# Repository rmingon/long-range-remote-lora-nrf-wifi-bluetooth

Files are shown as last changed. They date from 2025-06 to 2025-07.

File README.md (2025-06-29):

# **Triple-Radio Remote Controller PCB**

A compact, hand-held remote that combines **Wi-Fi / Bluetooth (ESP32)**, **2.4 GHz nRF24L01+** and **868/915 MHz LoRa (RFM95W)** in a single, joystick-style board.  
It is intended as a flexible radio interface for robotics, drones, RC models, telemetry links or IoT experimentation where different wireless technologies are useful at once.

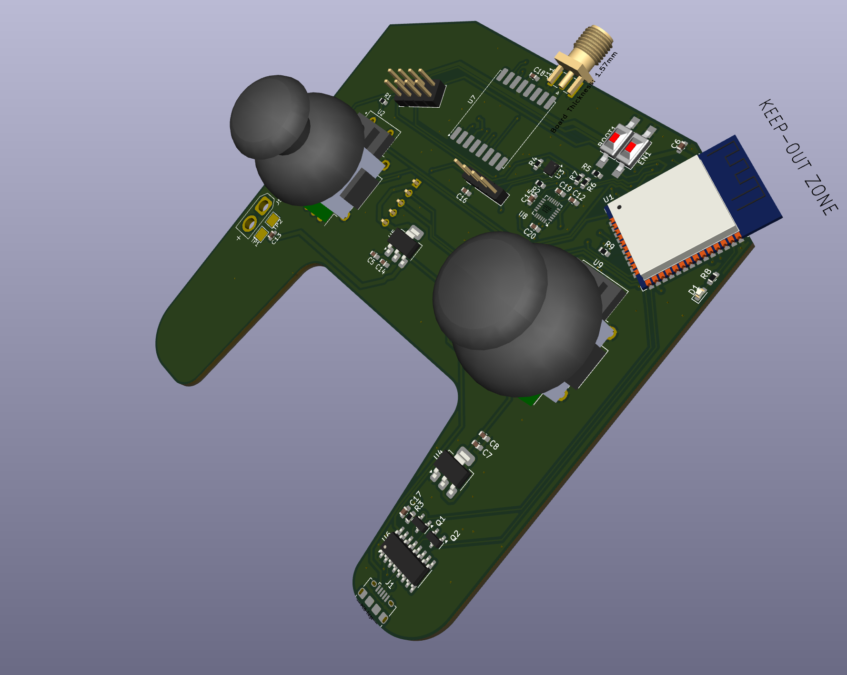
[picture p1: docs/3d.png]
3 D render
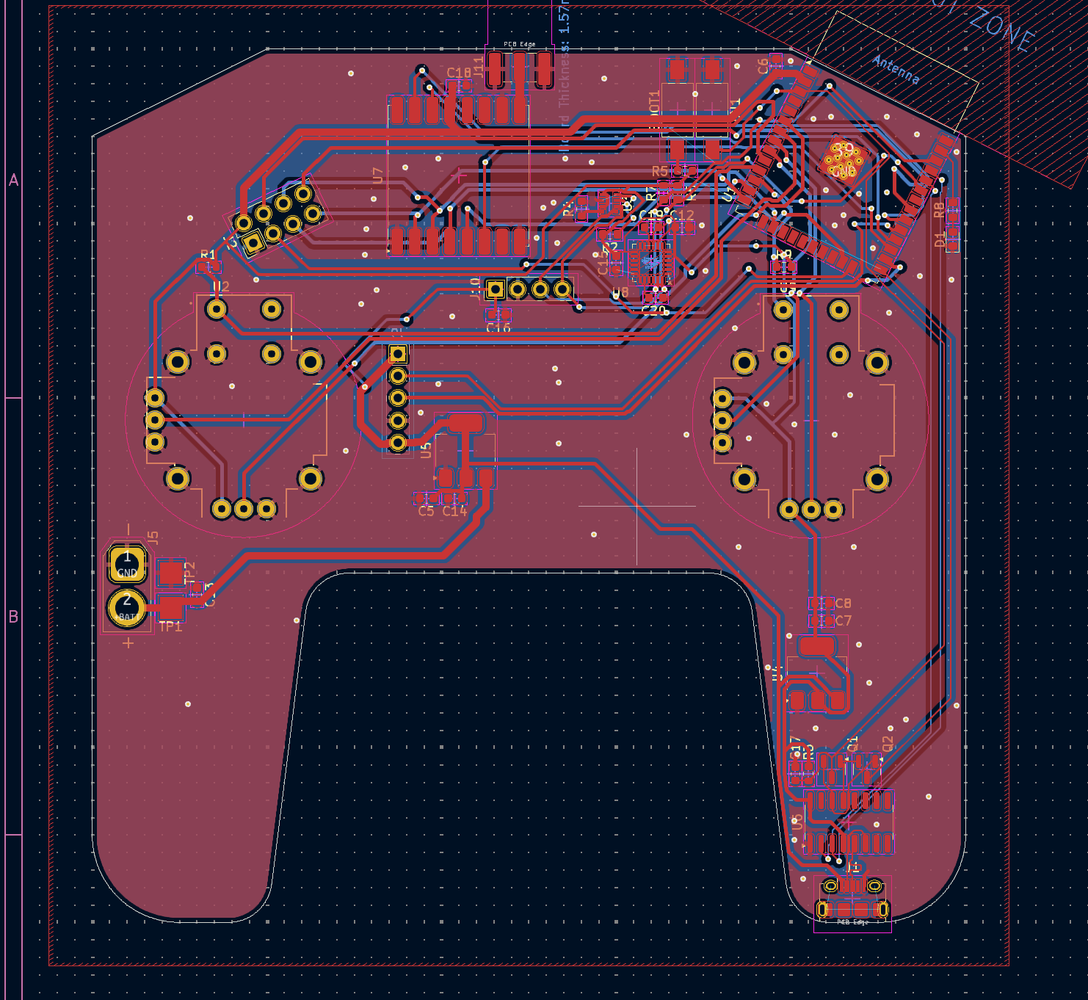
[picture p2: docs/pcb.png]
Top copper
|  |  |
| --- | --- |

---

## Table of Contents
1. [Features](#features)  
2. [Hardware Overview](#hardware-overview)  
3. [Schematic Blocks](#schematic-blocks)  
4. [Power Architecture](#power-architecture)  
5. [Pin Map](#pin-map)  
6. [Firmware](#firmware)  
7. [Getting Started](#getting-started)  
8. [Directory Layout](#directory-layout)  
9. [Road-Map](#road-map)  
10. [License](#license)

---

## Features
* **MCU — ESP32-WROOM-32**  
  * Dual-core Xtensa @ 240 MHz, 520 KB SRAM  
  * Integrated Wi-Fi 802.11 b/g/n + Bluetooth Classic/LE  
* **Radios**  
  * **nRF24L01+** – 2.4 GHz packet radio via 8-pin vertical socket  
  * **RFM95W** – Semtech SX1276 LoRa transceiver, SMA edge connector (keep-out ensured)  
* **Controls**  
  * Dual analog thumb joysticks (SparkFun COM-09032) with push-buttons  
  * One user LED (GPIO-controlled)  
* **Sensors**  
  * **MPU-6050** 6-axis IMU (gyro + accel)  
  * **BMP-280** barometric pressure / temperature sensor  
* **USB & Programming**  
  * On-board CH340C USB-to-UART with auto-reset/boot circuitry  
  * Standard USB-C connector (5 V input & data)  
* **Power**  
  * 2-pin JST-PH for Li-Ion/Li-Po battery (“+BATT”)  
  * AMS1117-3 V3 LDO for logic / radios  
  * AMS1117-5 V rail for external accessories (ESC, servos, etc.)  
  * Reverse-polarity and inrush-limit protections  
* **Expansion / Debug**  
  * 5-pin 5 V UART header  
  * 4-pin 5 V I²C header  
  * Plenty of un-populated GPIO test-pads on bottom layer  
* Finished board: **74 mm × 74 mm**, 2-layer, ENIG, green solder-mask.

---

## Hardware Overview
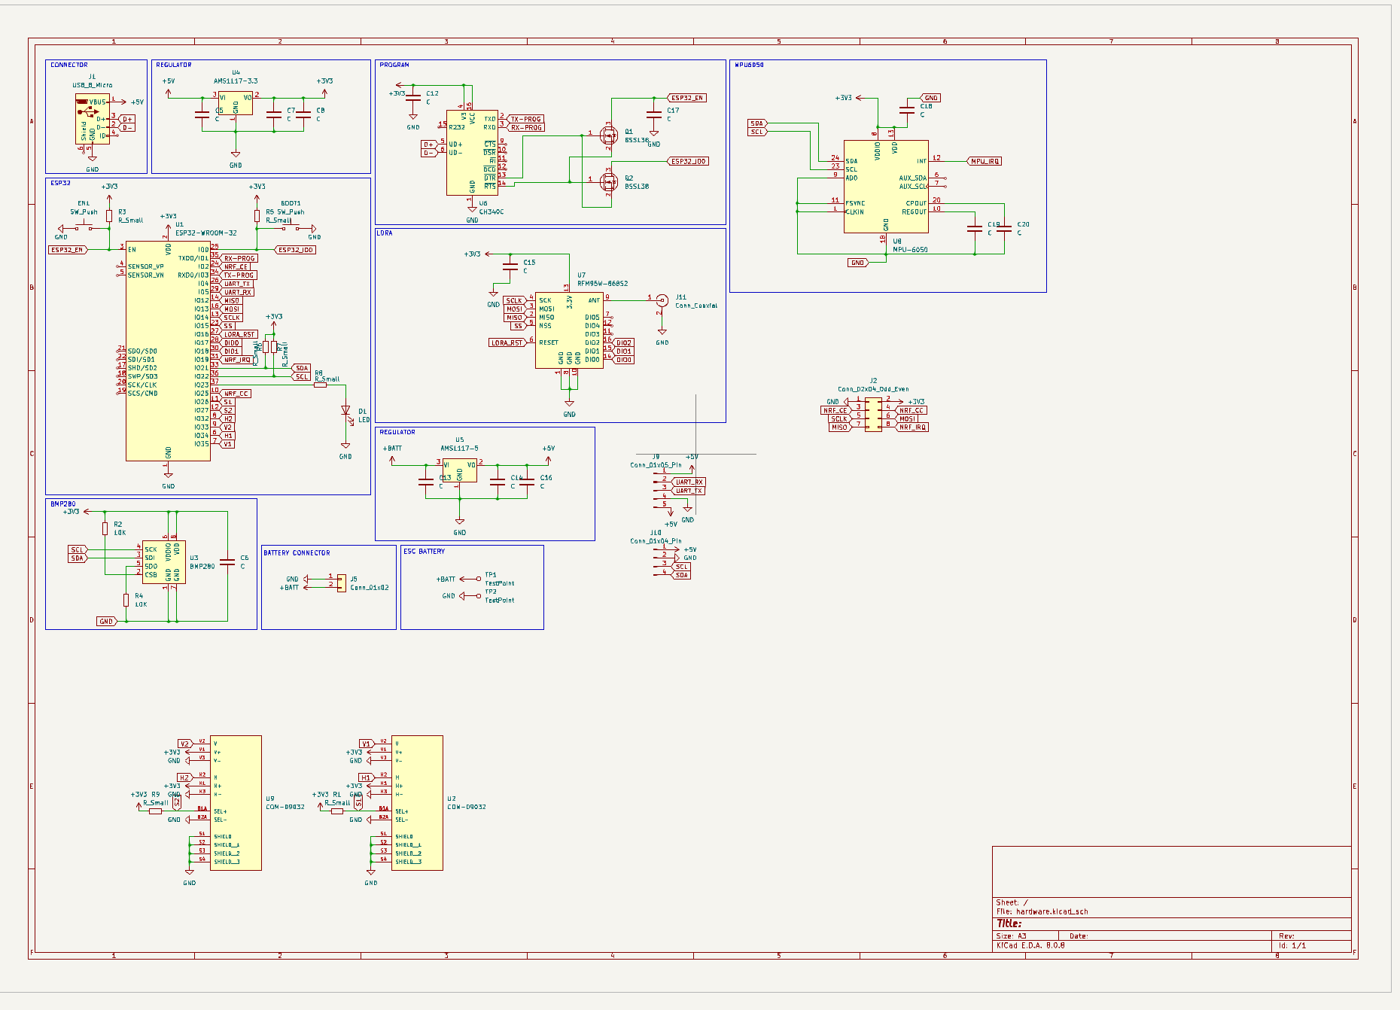
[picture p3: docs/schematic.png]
High-level block diagram


| Block | Purpose | Interfaces |
|---|---|---|
| ESP32-WROOM-32 | Central MCU; Wi-Fi/BLE | SPI, I²C, UART, ADC |
| RFM95W-868/915 | Long-range LoRa | SPI (SCK/MISO/MOSI/SS) + DIO0/1/2 + RESET |
| nRF24L01+ socket | Low-latency 2.4 GHz | Same SPI bus, CE/CSN/IRQ lines |
| MPU-6050 | Motion sensing | I²C @ 400 kHz |
| BMP-280 | Altitude / temp | I²C (wired for I²C) |
| Dual joysticks | User input | 4 × ADC + 2 × GPIO (switches) |
| CH340C | USB-UART | UART 0 (TX0/RX0), DTR/RTS auto reset |
| AMS1117-3 V3 | Logic 3.3 V rail | Up to 1 A |
| AMS1117-5 V | Aux 5 V rail | Up to 1 A |

---

## Power Architecture
```
Li-Po 2S
        │
        ├─ AMS1117-5 V ───► 5 V header / accessories
        │
        └─ AMS1117-3 V3 ──► ESP32, sensors, radios (on-board)
```
The micro-USB port supplies 5 V when plugged; if a battery is present it is **not charged** – add an external charger if required.

---

## Pin Map

| Signal | ESP32 GPIO | Notes |
|---|---|---|
| **LoRa (RFM95W)** |||
| LORA_SS (NSS) | 5 | Shared SPI SS |
| LORA_RST | 26 | Active-low reset |
| LORA_DIO0 | 34 | IRQ – input-only |
| LORA_DIO1 | 35 | Optional |
| **nRF24L01+** |||
| NRF_SS (CSN) | 33 |
| NRF_CE | 32 |
| NRF_IRQ | 27 |
| **Shared SPI bus** |||
| SCK | 18 |
| MOSI | 23 |
| MISO | 19 |
| **I²C bus** |||
| SDA | 21 | MPU-6050, BMP-280, external header |
| SCL | 22 |
| **Joysticks** |||
| Stick-L H | 36 (ADC1_0) |
| Stick-L V | 39 (ADC1_3) |
| Stick-R H | 34 (ADC1_6) |
| Stick-R V | 35 (ADC1_7) |
| Stick-L Btn | 13 |
| Stick-R Btn | 12 |
| **USB-UART** |||
| TX0 | 1 |
| RX0 | 3 |
| DTR / RTS | Auto-reset circuit |

All unused pins are broken out to pads for hacking.

---

## Firmware

Any ESP32 framework will work; the board is tested with **PlatformIO + Arduino**.  
Example `platformio.ini` snippet:

```ini
[env:esp32-remote]
platform      = espressif32
board         = esp32dev
framework     = arduino
monitor_speed = 115200
build_flags   =
  -D LORA_SS=5
  -D LORA_RST=26
  -D LORA_DIO0=34
  -D NRF_CE=32
  -D NRF_CS=33
  -D NRF_IRQ=27
lib_deps =
  sandeepmistry/LoRa
  maniacbug/RF24
  adafruit/Adafruit MPU6050
  adafruit/Adafruit BMP280 Library
```

---

## Getting Started

1. **Clone** the repository  

   ```bash
   git clone git@github.com:rmingon/long-range-remote-lora-nrf-wifi-bluetooth.git
   cd long-range-remote-lora-nrf-wifi-bluetooth
   ```

2. **Install PlatformIO** (VS Code extension or CLI).  
3. **Select the env** in `platformio.ini`, edit radio pins if you changed the board.  
4. **Connect micro-USB** ch340 auto-programming.  
5. Verify serial output at **115 200 baud**.

### LoRa / nRF24L01+ demos
Example sketches are in `firmware/examples/`:

* `lora_ping/` – bidirectional ping using SX1276  
* `rf24_controller/` – joystick values sent every 20 ms to a base-station  
* `wifi_update/` – OTA update via Wi-Fi AP  

Build & flash with:

```bash
pio run -e esp32-remote -t upload -d firmware/examples/lora_ping
```

---

## Directory Layout
```
.
├─ firmware/              → PlatformIO source
├─ hardware/
│  ├─ kicad/              → .kicad_pcb, .sch, libraries
│  ├─ gerber/             → ready for fabrication
│  └─ stl/                → optional enclosure models
├─ docs/
│  ├─ img/                → renders & photos used in README
│  └─ datasheets/
└─ LICENSE
```

---

## Road-Map
* Li-Po charging / fuel-gauge on-board  
* Hall-effect joysticks option  
* Enclosure with TPU grips  
* Support for 900 MHz nRF905 as fourth radio

---

## License
Hardware is released under **CERN-OHL-S v2**.  
Firmware samples are **MIT**.  
See individual source files for details.

---

*If you make something cool with this board, please open a pull-request and show it off!*

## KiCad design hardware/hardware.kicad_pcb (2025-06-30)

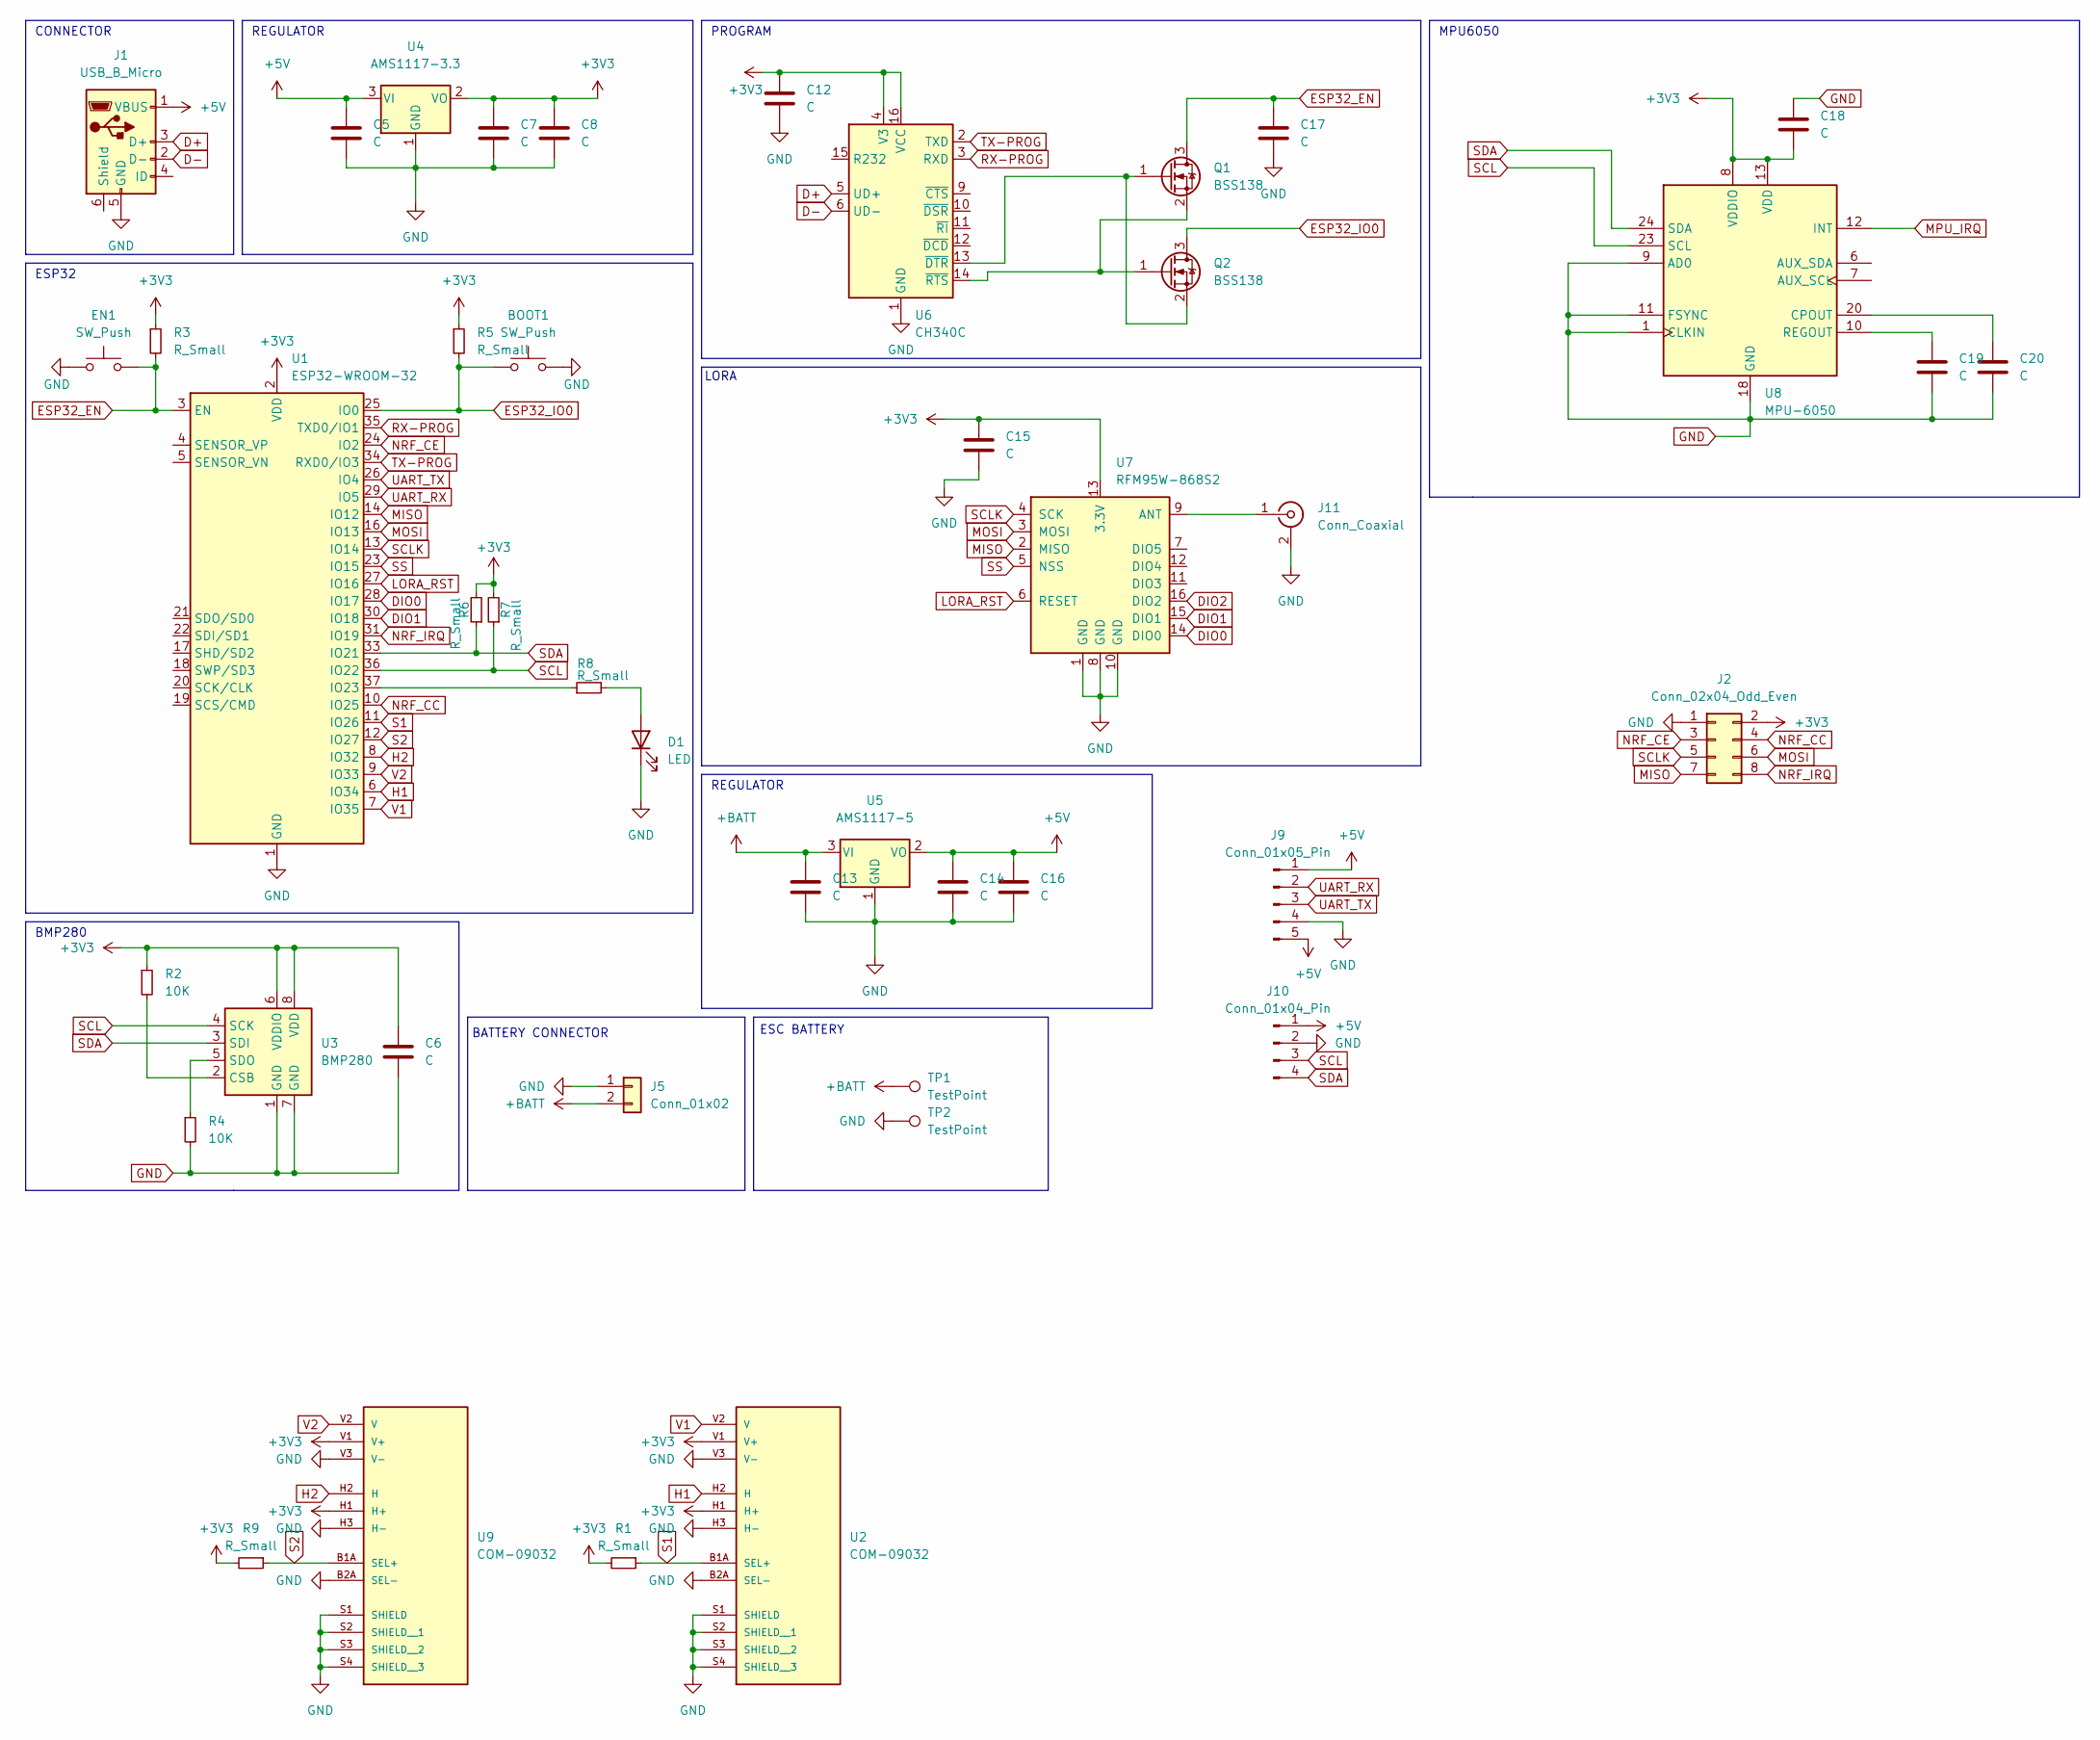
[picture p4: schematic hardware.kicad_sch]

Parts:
BOOT1: SW_Push; SW_SPST_FSMSM
C5, C6, C7, C8, C12, C13, C14, C15, C16, C17, C18, C19, C20: C; C_0603_1608Metric
D1: LED; LED_0603_1608Metric
EN1: SW_Push; SW_SPST_FSMSM
J1: USB_B_Micro; USB_Micro-B_Amphenol_10118194_Horizontal
J2: Conn_02x04_Odd_Even; PinHeader_2x04_P2.54mm_Vertical
J5: Conn_01x02; AMASS_XT30U-F_1x02_P5.0mm_Vertical
J9: Conn_01x05_Pin; PinHeader_1x05_P2.54mm_Vertical
J10: Conn_01x04_Pin; PinHeader_1x04_P2.54mm_Vertical
J11: Conn_Coaxial; SMA_Samtec_SMA-J-P-H-ST-EM1_EdgeMount
Q1, Q2: BSS138; SOT-23
R1, R3, R5, R6, R7, R8, R9: R_Small; R_0603_1608Metric
R2, R4: 10K; R_0603_1608Metric
TP1, TP2: TestPoint; TestPoint_Pad_2.5x2.5mm
U1: ESP32-WROOM-32
U2, U9: COM-09032; XDCR_COM-09032; PARTREV N/A
U3: BMP280; Bosch_LGA-8_2x2.5mm_P0.65mm_ClockwisePinNumbering
U4: AMS1117-3.3; SOT-223-3_TabPin2
U5: AMS1117-5; SOT-223-3_TabPin2
U6: CH340C; SOIC-16_3.9x9.9mm_P1.27mm
U7: RFM95W-868S2; HOPERF_RFM9XW_SMD
U8: MPU-6050; InvenSense_QFN-24_4x4mm_P0.5mm

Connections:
+3V3: C6.1, C7.1, C8.1, C12.1, C15.1, C18.2, J2.2, R1.2, R2.1, R3.1, R5.1, R6.2, R7.2, R9.2, U1.2 (VDD), U2.H1 (H+), U2.V1 (V+), U3.6 (VDDIO), U3.8 (VDD), U4.2 (VO), U6.4 (V3), U6.16 (VCC), U7.13 (3.3V), U8.8 (VDDIO), U8.13 (VDD), U9.H1 (H+), U9.V1 (V+)
+5V: C5.1, C14.1, C16.1, J1.1 (VBUS), J9.1, J9.5, J10.1, U4.3 (VI), U5.2 (VO)
+BATT: C13.1, J5.2, TP1.1, U5.3 (VI)
D+: J1.3 (D+), U6.5 (UD+)
D-: J1.2 (D-), U6.6 (UD-)
DIO0: U1.28 (IO17), U7.14 (DIO0)
DIO1: U1.30 (IO18), U7.15 (DIO1)
DIO2: U7.16 (DIO2)
ESP32_EN: C17.1, EN1.2, Q1.3 (D), R3.2, U1.3 (EN)
ESP32_IO0: BOOT1.1, Q2.3 (D), R5.2, U1.25 (IO0)
GND: BOOT1.2, C5.2, C6.2, C7.2, C8.2, C12.2, C13.2, C14.2, C15.2, C16.2, C17.2, C18.1, C19.2, C20.2, D1.1 (K), EN1.1, J1.5 (GND), J2.1, J5.1, J9.4, J10.2, J11.2 (Ext), R4.2, TP2.1, U1.1 (GND), U1.15 (GND), U1.38 (GND), U1.39 (GND), U2.B2A (SEL-), U2.H3 (H-), U2.S1 (SHIELD), U2.S2 (SHIELD__1), U2.S3 (SHIELD__2), U2.S4 (SHIELD__3), U2.V3 (V-), U3.1 (GND), U3.7 (GND), U4.1 (GND), U5.1 (GND), U6.1 (GND), U7.1 (GND), U7.8 (GND), U7.10 (GND), U8.1 (CLKIN), U8.9 (AD0), U8.11 (FSYNC), U8.18 (GND), U9.B2A (SEL-), U9.H3 (H-), U9.S1 (SHIELD), U9.S2 (SHIELD__1), U9.S3 (SHIELD__2), U9.S4 (SHIELD__3), U9.V3 (V-)
H1: U1.6 (IO34), U2.H2 (H)
H2: U1.8 (IO32), U9.H2 (H)
LORA_RST: U1.27 (IO16), U7.6 (RESET)
MISO: J2.7, U1.14 (IO12), U7.2 (MISO)
MOSI: J2.6, U1.16 (IO13), U7.3 (MOSI)
MPU_IRQ: U8.12 (INT)
NRF_CC: J2.4, U1.10 (IO25)
NRF_CE: J2.3, U1.24 (IO2)
NRF_IRQ: J2.8, U1.31 (IO19)
unnamed: D1.2 (A), R8.2
unnamed: J11.1 (In), U7.9 (ANT)
unnamed: Q1.1 (G), Q2.2 (S), U6.13 (~DTR)
unnamed: Q1.2 (S), Q2.1 (G), U6.14 (~RTS)
unnamed: R8.1, U1.37 (IO23)
unnamed: R2.2, U3.2 (CSB)
unnamed: R4.1, U3.5 (SDO)
unnamed: C20.1, U8.20 (CPOUT)
unnamed: C19.1, U8.10 (REGOUT)
RX-PROG: U1.35 (TXD0/IO1), U6.3 (RXD)
S1: R1.1, U1.11 (IO26), U2.B1A (SEL+)
S2: R9.1, U1.12 (IO27), U9.B1A (SEL+)
SCL: J10.3, R7.1, U1.36 (IO22), U3.4 (SCK), U8.23 (SCL)
SCLK: J2.5, U1.13 (IO14), U7.4 (SCK)
SDA: J10.4, R6.1, U1.33 (IO21), U3.3 (SDI), U8.24 (SDA)
SS: U1.23 (IO15), U7.5 (NSS)
TX-PROG: U1.34 (RXD0/IO3), U6.2 (TXD)
UART_RX: J9.2, U1.29 (IO5)
UART_TX: J9.3, U1.26 (IO4)
V1: U1.7 (IO35), U2.V2 (V)
V2: U1.9 (IO33), U9.V2 (V)

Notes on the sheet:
CONNECTOR
REGULATOR
MPU6050
BMP280
ESC BATTERY
LORA
PROGRAM
ESP32
BATTERY CONNECTOR

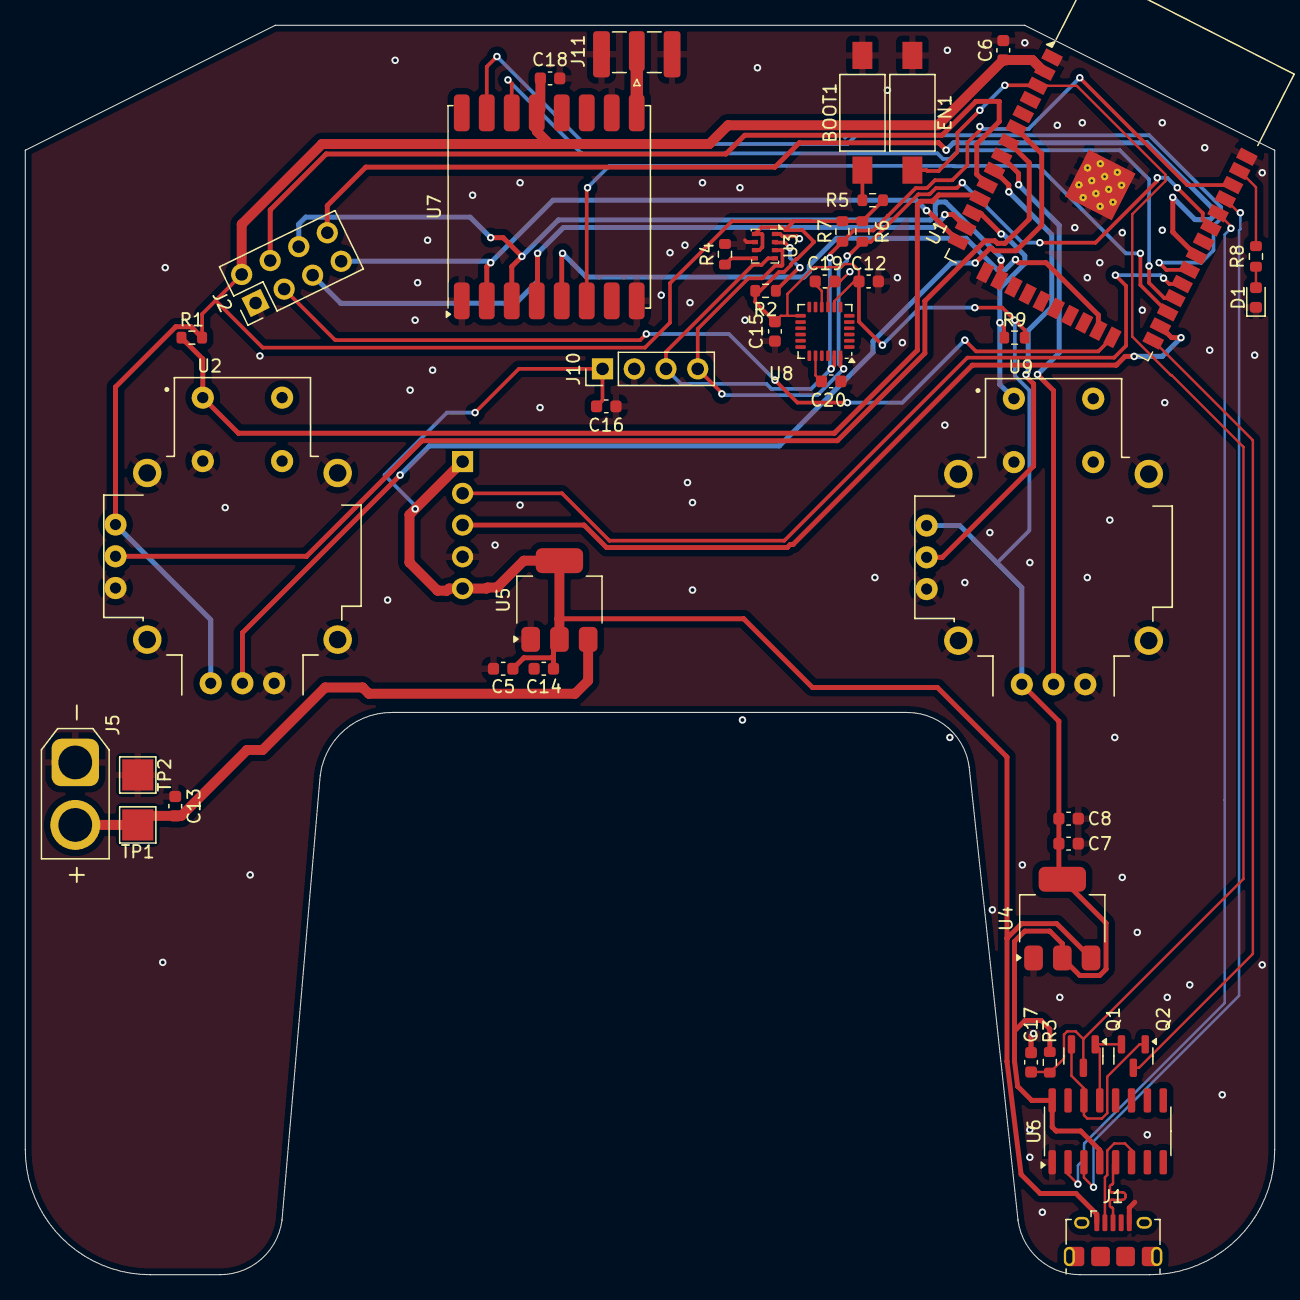
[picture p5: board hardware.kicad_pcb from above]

Board: 2 copper layers, 100.0 x 100.0 mm, 44 parts (1 on the bottom side), 39 nets.

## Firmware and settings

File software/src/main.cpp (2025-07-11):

#include <Arduino.h>
#include <SPI.h>
#include <RF24.h>
#include <ArduinoJson.h>

#define CE_PIN 2
#define CSN_PIN 25

SPIClass hspi(HSPI);
RF24 radio(CE_PIN, CSN_PIN); // Create RF24 object

#define LED 23

#define S1 26
#define H1 34
#define V1 35

#define S2 27
#define H2 32
#define V2 33

const byte address[6] = "NODE1";

void setup()
{
  pinMode(S1, INPUT);
  pinMode(H1, INPUT);
  pinMode(V1, INPUT);
  pinMode(S2, INPUT);
  pinMode(H2, INPUT);
  pinMode(V2, INPUT);

  hspi.begin(14, 12, 13, CSN_PIN); // SCLK, MISO, MOSI, SS

  Serial.begin(9600);
  delay(1000);

  // Set SPI interface used by RF24
  radio.begin(&hspi);

  if (!radio.isChipConnected())
  {
    Serial.println("nRF24L01 not detected!");
    while (1)
      ;
  }

  Serial.println("nRF24L01 transmitter ready.");

  pinMode(LED, OUTPUT);
  digitalWrite(LED, HIGH);
}

void loop()
{

  JsonDocument doc;

  doc["S1"] = digitalRead(S1);
  doc["H1"] = (analogRead(H1) - 2048) / 20;
  doc["V1"] = (analogRead(V1) - 2048) / 20;
  doc["S2"] = digitalRead(S2);
  doc["H2"] = (analogRead(H2) - 2048) / 20;
  doc["V2"] = (analogRead(V2) - 2048) / 20;

  String output;
  serializeJson(doc, output);

  Serial.println(output);
  delay(100);
}

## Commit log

2025-06-29 wiring + pcb + componants
    [hardware.kicad_pcb, hardware.kicad_sch]
2025-06-30 update pcb size
    [hardware.kicad_pcb]
